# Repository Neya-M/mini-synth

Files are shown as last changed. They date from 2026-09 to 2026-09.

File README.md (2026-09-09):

# mini-synth

A synth but you can only play frequencies received from light, humidity, and temperature sensors.

Schematic:

two of the buttons are upside down for easier routing :P



PCB:



3D View:



BOM:

|Id|Designator|Footprint|Quantity|Designation|Supplier and ref|
|-|-|-|-|-|-|
|1|U4|QFN-20-1EP_4x4mm_P0.5mm_EP2.7x2.7mm|1|MCP23008-xML|https://www.lcsc.com/product-detail/C144211.html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|
|2|C10|C_0402_1005Metric|1|2.2uF|https://www.lcsc.com/product-detail/C170151.html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|
|3|SW3|RotaryEncoder_Alps_EC12E-Switch_Vertical_H20mm|1|volume|https://www.lcsc.com/product-detail/C255515.html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|
|4|J4|PinHeader_1x04_P2.54mm_Vertical|1|weaker pins|no part|
|5|"C31|C32|C17|C3|C2|C4|C13|C18|C1|C19|C16|C6"|C_0402_1005Metric|12|100nF|https://www.lcsc.com/product-detail/C60474.html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|
|6|"R19|R5|R11|R8|R6"|R_0402_1005Metric|5|10K|https://www.lcsc.com/product-detail/C60490.html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|
|7|"C8|C9|C7"|C_0402_1005Metric|3|1uF|https://www.lcsc.com/product-detail/C87145.html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|
|8|"REF**|REF**|REF**"|capacitive touch button 10mm|3|capacitive touch button 10mm|no part|
|9|R21|SW-TH_PRS11R-415F-S103B1|1|20K|https://www.lcsc.com/product-detail/C17371045.html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|
|10|R1|R_LDR_5.1x4.3mm_P3.4mm_Vertical|1|R_Photo|https://www.lcsc.com/product-detail/C125630.html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|
|11|U7|WQFN-16-1EP_3x3mm_P0.5mm_EP1.6x1.6mm_ThermalVias|1|TPA6132A2RTE|https://www.lcsc.com/product-detail/C69901.html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|
|12|SW2|RotaryEncoder_Alps_EC12E-Switch_Vertical_H20mm|1|pitch|https://www.lcsc.com/product-detail/C255515.html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|
|13|SW14|SW-TH_RKJXL100401V|1|SW_Rotary_1x8_MP|https://www.lcsc.com/product-detail/C160838.html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|
|14|"C11|C12|C5"|C_0402_1005Metric|3|4.7uF|https://www.lcsc.com/product-detail/C368809.html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|
|15|C25|C_0402_1005Metric|1|4.7uF|https://www.lcsc.com/product-detail/C368809.html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|
|16|SW7|SW-SMD_L6.1-W3.7-LS8.0-1|1|BOOT|https://www.lcsc.com/product-detail/C49234126.html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|
|17|"R13|R12|R9|R7"|R_0402_1005Metric|4|15K|https://www.lcsc.com/product-detail/C2909322.html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|
|18|"D8|D3|D1|D5|D4|D7|D6|D2"|LED-SMD_4P-L3.2-W2.8-LS5.9_SK6812MINI-E|8|SK6812|https://www.lcsc.com/product-detail/C5149201.html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|
|19|U6|TSSOP-14_L5.0-W4.4-P0.65-LS6.4-BL|1|"74HCT125PW|118"|https://www.lcsc.com/product-detail/C131316.html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|
|20|J1|USB-C-SMD_G-SWITCH_GT-USB-7010ASV|1|USB_C_Receptacle_USB2.0_14P|https://www.lcsc.com/product-detail/C2988369.html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|
|21|SW1|KEY-TH_L12.0-W3.3-P5.00|1|reset|https://www.lcsc.com/product-detail/C2888728.html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|
|22|R20|R_0402_1005Metric|1|330|https://www.lcsc.com/product-detail/C105875.html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|
|23|"D10|D16|D9|D11|D14|D12|D13|D17|D15"|D_0402_1005Metric|9|D|https://www.lcsc.com/product-detail/C28646371.html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|
|24|R22|R_0402_1005Metric|1|1K|https://www.lcsc.com/product-detail/C106235.html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|
|25|SW9|SW-TH_XKB5858-Z-E|1|loop 2|https://www.lcsc.com/product-detail/C780038.html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|
|26|CN1|AUDIO-TH_HOOYA_PJ-320|1|trs headphone jack|https://www.lcsc.com/product-detail/C2939180.html?s_z=n_q_C2939180&globalKeyword=C2939180|
|27|U5|LQFP-48_7x7mm_P0.5mm|1|CH32V203C8T6|https://www.lcsc.com/product-detail/C3001172.html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|
|28|"C30|C29"|C_0402_1005Metric|2|10uF|https://www.lcsc.com/product-detail/C315248.html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|
|29|C23|C_0402_1005Metric|1|10uF|https://www.lcsc.com/product-detail/C315248.html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|
|30|U2|Sensirion_DFN-4_1.5x1.5mm_P0.8mm_SHT4x_NoCentralPad|1|SHT4x|https://www.lcsc.com/product-detail/C55108905.html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|
|31|"C24|C21"|C_0402_1005Metric|2|560pF|https://www.lcsc.com/product-detail/C315248.html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|
|32|"C14|C15"|C_0402_1005Metric|2|47uf|https://www.lcsc.com/product-detail/C140782.html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|
|33|"R16|R15"|R_0402_1005Metric|2|27|https://www.lcsc.com/product-detail/C2100055.html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|
|34|U3|SOT-23|1|MCP1700x-330xxTT|https://www.lcsc.com/product-detail/C144211.html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|
|35|SW10|SW-TH_XKB5858-Z-E|1|record|https://www.lcsc.com/product-detail/C780038.html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|
|36|"R4|R18|R17"|R_0402_1005Metric|3|4.7K|https://www.lcsc.com/product-detail/C105871.html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|
|37|SW12|KEY-TH_L12.0-W3.3-P5.00|1|free1|https://www.lcsc.com/product-detail/C2888728.html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|
|38|SW11|KEY-TH_L12.0-W3.3-P5.00|1|delay|https://www.lcsc.com/product-detail/C2888728.html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|
|39|"R3|R2"|R_0402_1005Metric|2|5.1K|https://www.lcsc.com/product-detail/C105872.html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|
|40|SW13|KEY-TH_L12.0-W3.3-P5.00|1|free2|https://www.lcsc.com/product-detail/C2888728.html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|
|41|R14|R_0402_1005Metric|1|100K|https://www.lcsc.com/product-detail/C60491.html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|
|42|"FB2|FB1"|L0402|2|FerriteBead_Small|https://www.lcsc.com/product-detail/C17701320.html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|
|43|C22|C_0402_1005Metric|1|10nF|https://www.lcsc.com/product-detail/C15195.html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|
|44|U1|DIP-16_W7.62mm|1|PT2399|https://www.lcsc.com/product-detail/C84963.html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|
|45|"C20|C26"|C_0402_1005Metric|2|5.6nF|https://www.lcsc.com/product-detail/C281760.html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|
|46|J2|PinHeader_1x02_P2.54mm_Vertical|1|analog|no part|
|47|SW8|SW-SMD_L6.1-W3.7-LS8.0-1|1|RESET|https://www.lcsc.com/product-detail/C49234126.html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|
|48|"C28|C27"|C_0402_1005Metric|2|12pF|https://www.lcsc.com/product-detail/C26406.html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|
|49|Y1|CRYSTAL-SMD_4P-L3.2-W2.5-BL|1|8MHz|https://www.lcsc.com/product-detail/C2682775.html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|
|50|SW4|SW-SMD_L6.1-W3.7-LS8.0-1|1|reset2|https://www.lcsc.com/product-detail/C49234126.html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|
|51|R10|R_0603_1608Metric|1|2.7K|https://www.lcsc.com/product-detail/C2907008.html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|
|52|J3|PinHeader_1x04_P2.54mm_Vertical|1|debug header|no part|

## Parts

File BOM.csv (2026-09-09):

Id | Designator | Footprint | Quantity | Designation | Supplier and ref
1 | U4 | QFN-20-1EP_4x4mm_P0.5mm_EP2.7x2.7mm | 1 | MCP23008-xML | https://www.lcsc.com/product-detail/C144211.html
2 | C10 | C_0402_1005Metric | 1 | 2.2uF | https://www.lcsc.com/product-detail/C170151.html?s_z=n_q_t_capacitor%25200402
3 | SW3 | RotaryEncoder_Alps_EC12E-Switch_Vertical_H20mm | 1 | volume | https://www.lcsc.com/product-detail/C255515.html?s_z=n_q_t_ec12e
4 | J4 | PinHeader_1x04_P2.54mm_Vertical | 1 | weaker pins | no part
5 | C31,C32,C17,C3,C2,C4,C13,C18,C1,C19,C16,C6 | C_0402_1005Metric | 12 | 100nF | https://www.lcsc.com/product-detail/C60474.html?s_z=n_q_t_capacitor%25200402
6 | R19,R5,R11,R8,R6 | R_0402_1005Metric | 5 | 10K | https://www.lcsc.com/product-detail/C60490.html?s_z=n_q_t_resistor%25200402
7 | C8,C9,C7 | C_0402_1005Metric | 3 | 1uF | https://www.lcsc.com/product-detail/C87145.html?s_z=n_q_t_capacitor%25200402
8 | REF**,REF**,REF** | capacitive touch button 10mm | 3 | capacitive touch button 10mm | no part
9 | R21 | SW-TH_PRS11R-415F-S103B1 | 1 | 20K | https://www.lcsc.com/product-detail/C17371045.html
10 | R1 | R_LDR_5.1x4.3mm_P3.4mm_Vertical | 1 | R_Photo | https://www.lcsc.com/product-detail/C125630.html
11 | U7 | WQFN-16-1EP_3x3mm_P0.5mm_EP1.6x1.6mm_ThermalVias | 1 | TPA6132A2RTE | https://www.lcsc.com/product-detail/C69901.html?s_z=n_q_TPA6132A2RTE
12 | SW2 | RotaryEncoder_Alps_EC12E-Switch_Vertical_H20mm | 1 | pitch | https://www.lcsc.com/product-detail/C255515.html?s_z=n_q_t_ec12e
13 | SW14 | SW-TH_RKJXL100401V | 1 | SW_Rotary_1x8_MP | https://www.lcsc.com/product-detail/C160838.html
14 | C11,C12,C5 | C_0402_1005Metric | 3 | 4.7uF | https://www.lcsc.com/product-detail/C368809.html?s_z=n_q_t_capacitor%25200402
15 | C25 | C_0402_1005Metric | 1 | 4.7uF | https://www.lcsc.com/product-detail/C368809.html?s_z=n_q_t_capacitor%25200402
16 | SW7 | SW-SMD_L6.1-W3.7-LS8.0-1 | 1 | BOOT | https://www.lcsc.com/product-detail/C49234126.html
17 | R13,R12,R9,R7 | R_0402_1005Metric | 4 | 15K | https://www.lcsc.com/product-detail/C2909322.html?s_z=n_q_t_resistor%25200402
18 | D8,D3,D1,D5,D4,D7,D6,D2 | LED-SMD_4P-L3.2-W2.8-LS5.9_SK6812MINI-E | 8 | SK6812 | https://www.lcsc.com/product-detail/C5149201.html?s_z=n_q_l_SK6812%2520mini%2520e
19 | U6 | TSSOP-14_L5.0-W4.4-P0.65-LS6.4-BL | 1 | 74HCT125PW,118 | https://www.lcsc.com/product-detail/C131316.html
20 | J1 | USB-C-SMD_G-SWITCH_GT-USB-7010ASV | 1 | USB_C_Receptacle_USB2.0_14P | https://www.lcsc.com/product-detail/C2988369.html
21 | SW1 | KEY-TH_L12.0-W3.3-P5.00 | 1 | reset | https://www.lcsc.com/product-detail/C2888728.html
22 | R20 | R_0402_1005Metric | 1 | 330 | https://www.lcsc.com/product-detail/C105875.html?s_z=n_q_t_resistor%25200402
23 | D10,D16,D9,D11,D14,D12,D13,D17,D15 | D_0402_1005Metric | 9 | D | https://www.lcsc.com/product-detail/C28646371.html?s_z=n_q_t_diode
24 | R22 | R_0402_1005Metric | 1 | 1K | https://www.lcsc.com/product-detail/C106235.html?s_z=n_q_t_resistor%25200402
25 | SW9 | SW-TH_XKB5858-Z-E | 1 | loop 2 | https://www.lcsc.com/product-detail/C780038.html
26 | CN1 | AUDIO-TH_HOOYA_PJ-320 | 1 | trs headphone jack | https://www.lcsc.com/product-detail/C2939180.html?s_z=n_q_C2939180&globalKeyword=C2939180
27 | U5 | LQFP-48_7x7mm_P0.5mm | 1 | CH32V203C8T6 | https://www.lcsc.com/product-detail/C3001172.html
28 | C30,C29 | C_0402_1005Metric | 2 | 10uF | https://www.lcsc.com/product-detail/C315248.html?s_z=n_q_t_capacitor%25200402
29 | C23 | C_0402_1005Metric | 1 | 10uF | https://www.lcsc.com/product-detail/C315248.html?s_z=n_q_t_capacitor%25200402
30 | U2 | Sensirion_DFN-4_1.5x1.5mm_P0.8mm_SHT4x_NoCentralPad | 1 | SHT4x | https://www.lcsc.com/product-detail/C55108905.html?s_z=n_q_t_sht4
31 | C24,C21 | C_0402_1005Metric | 2 | 560pF | https://www.lcsc.com/product-detail/C315248.html?s_z=n_q_t_capacitor%25200402
32 | C14,C15 | C_0402_1005Metric | 2 | 47uf | https://www.lcsc.com/product-detail/C140782.html?s_z=n_q_t_47%2520uF%2520capacitor
33 | R16,R15 | R_0402_1005Metric | 2 | 27 | https://www.lcsc.com/product-detail/C2100055.html?s_z=n_q_t_resistor%25200402
34 | U3 | SOT-23 | 1 | MCP1700x-330xxTT | https://www.lcsc.com/product-detail/C144211.html
35 | SW10 | SW-TH_XKB5858-Z-E | 1 | record | https://www.lcsc.com/product-detail/C780038.html
36 | R4,R18,R17 | R_0402_1005Metric | 3 | 4.7K | https://www.lcsc.com/product-detail/C105871.html?s_z=n_q_t_resistor%25200402
37 | SW12 | KEY-TH_L12.0-W3.3-P5.00 | 1 | free1 | https://www.lcsc.com/product-detail/C2888728.html
38 | SW11 | KEY-TH_L12.0-W3.3-P5.00 | 1 | delay | https://www.lcsc.com/product-detail/C2888728.html
39 | R3,R2 | R_0402_1005Metric | 2 | 5.1K | https://www.lcsc.com/product-detail/C105872.html?s_z=n_q_t_resistor%25200402
40 | SW13 | KEY-TH_L12.0-W3.3-P5.00 | 1 | free2 | https://www.lcsc.com/product-detail/C2888728.html
41 | R14 | R_0402_1005Metric | 1 | 100K | https://www.lcsc.com/product-detail/C60491.html?s_z=n_q_t_resistor%25200402
42 | FB2,FB1 | L0402 | 2 | FerriteBead_Small | https://www.lcsc.com/product-detail/C17701320.html
43 | C22 | C_0402_1005Metric | 1 | 10nF | https://www.lcsc.com/product-detail/C15195.html?s_z=n_q_t_capacitor%25200402
44 | U1 | DIP-16_W7.62mm | 1 | PT2399 | https://www.lcsc.com/product-detail/C84963.html?s_z=n_q_x_pt2399
45 | C20,C26 | C_0402_1005Metric | 2 | 5.6nF | https://www.lcsc.com/product-detail/C281760.html?s_z=n_q_t_capacitor%25200402
46 | J2 | PinHeader_1x02_P2.54mm_Vertical | 1 | analog | no part
47 | SW8 | SW-SMD_L6.1-W3.7-LS8.0-1 | 1 | RESET | https://www.lcsc.com/product-detail/C49234126.html
48 | C28,C27 | C_0402_1005Metric | 2 | 12pF | https://www.lcsc.com/product-detail/C26406.html?s_z=n_q_t_capacitor%25200402
49 | Y1 | CRYSTAL-SMD_4P-L3.2-W2.5-BL | 1 | 8MHz | https://www.lcsc.com/product-detail/C2682775.html
50 | SW4 | SW-SMD_L6.1-W3.7-LS8.0-1 | 1 | reset2 | https://www.lcsc.com/product-detail/C49234126.html
51 | R10 | R_0603_1608Metric | 1 | 2.7K | https://www.lcsc.com/product-detail/C2907008.html?s_z=n_q_t_resistor%25200603%25202.7k
52 | J3 | PinHeader_1x04_P2.54mm_Vertical | 1 | debug header | no part

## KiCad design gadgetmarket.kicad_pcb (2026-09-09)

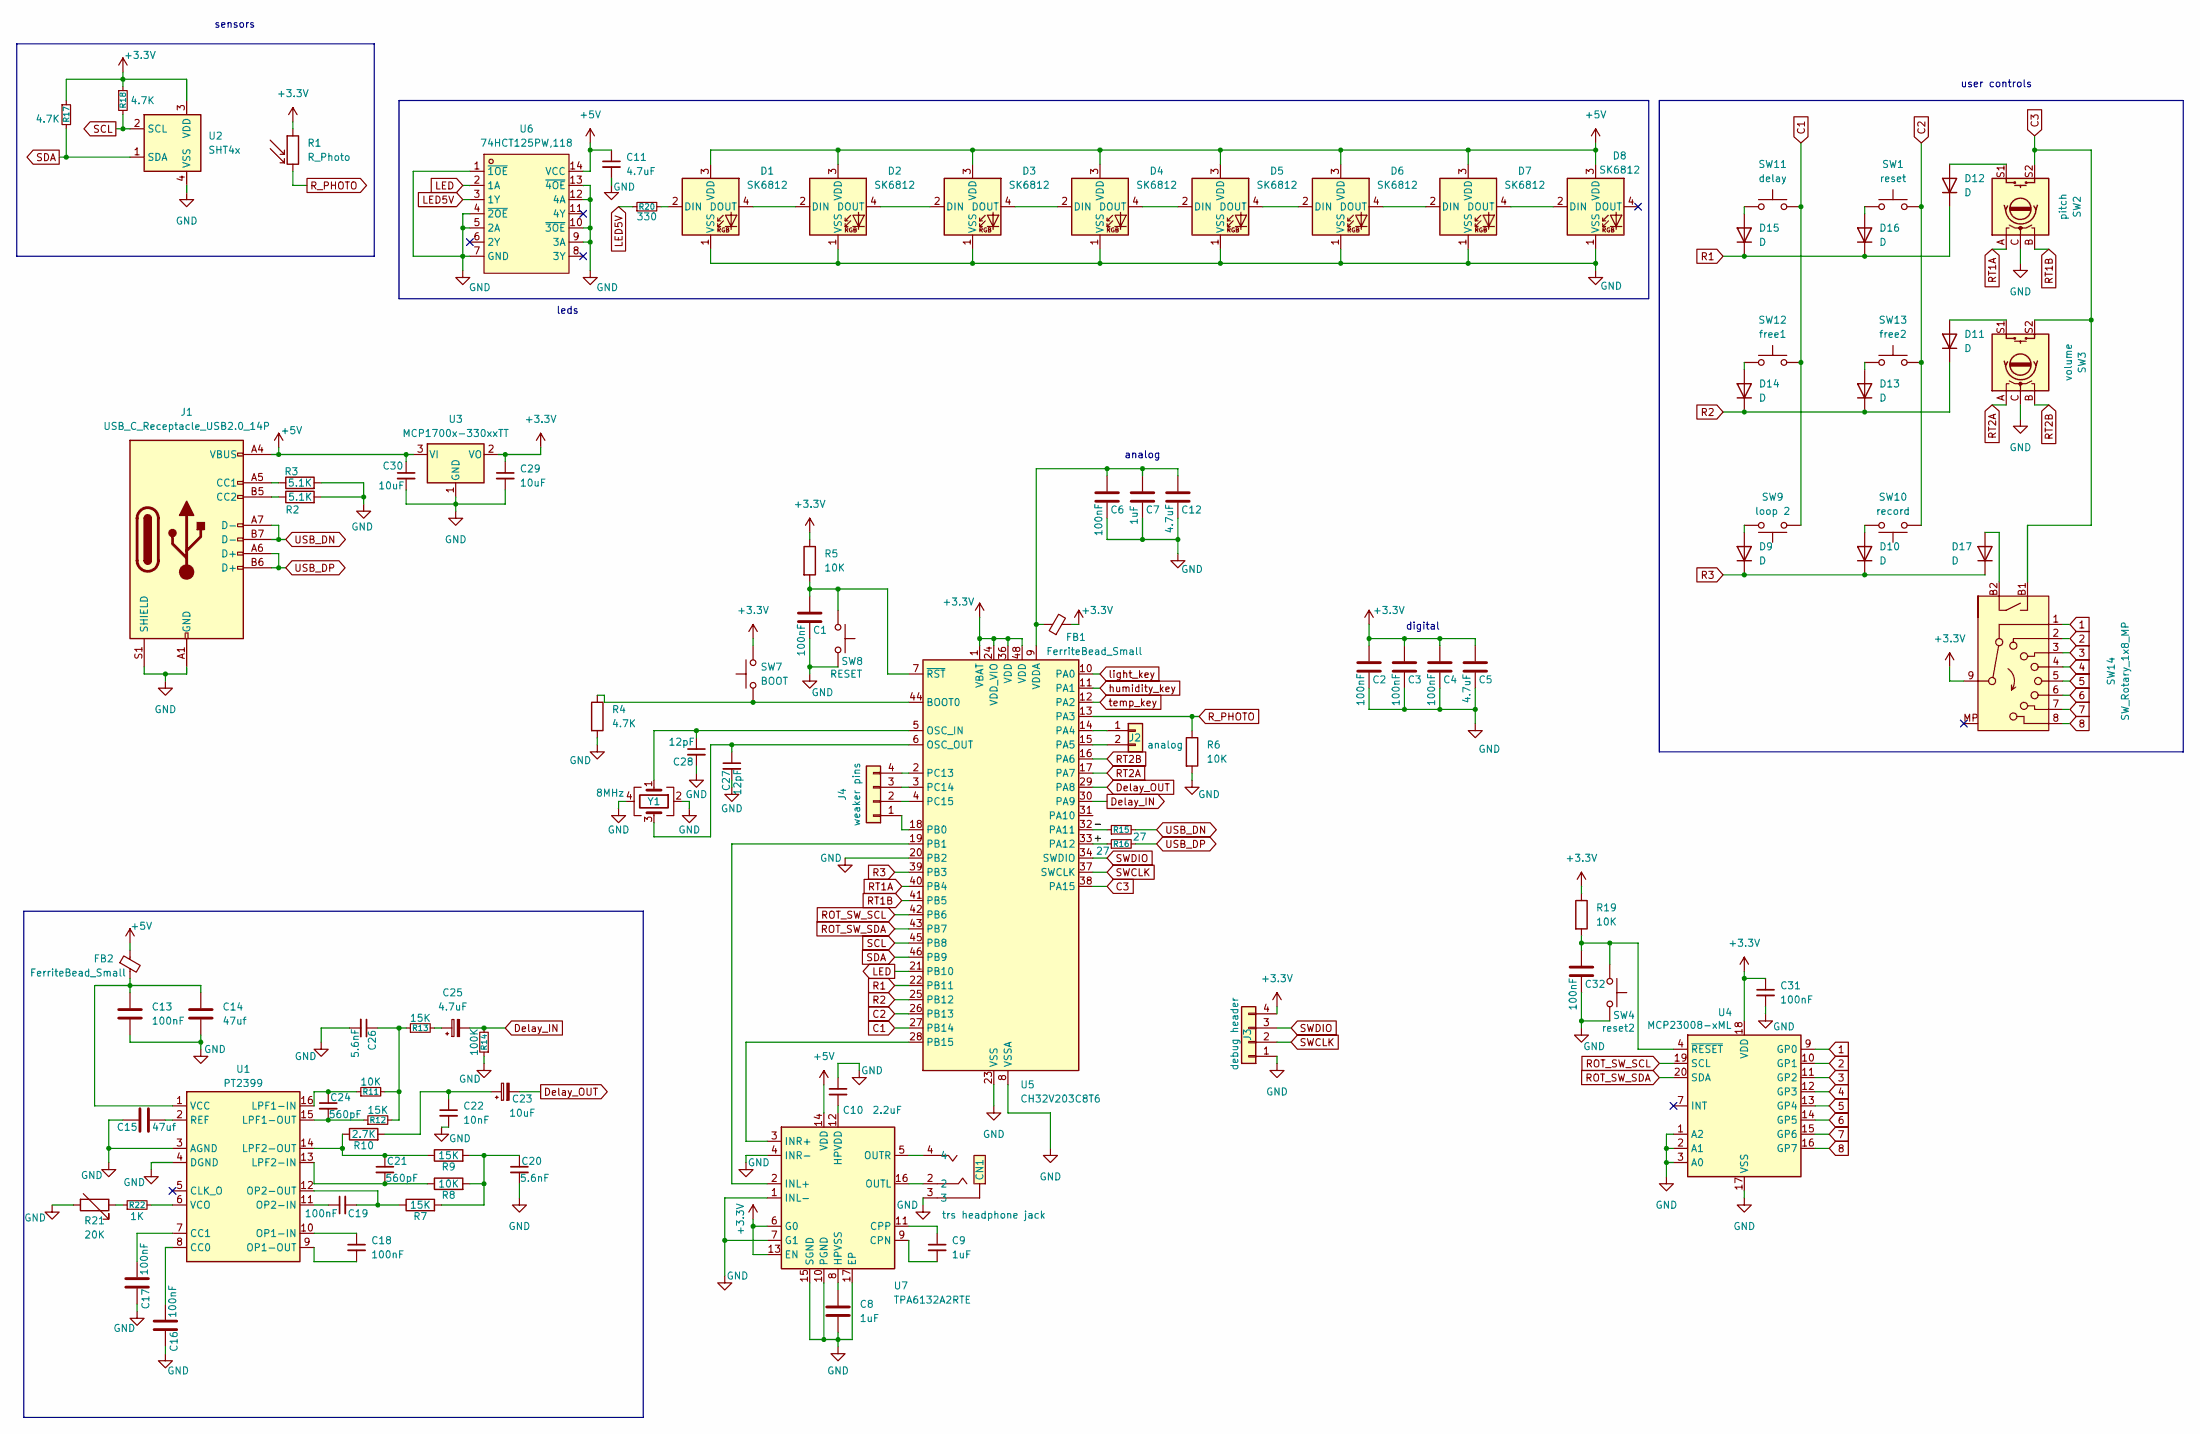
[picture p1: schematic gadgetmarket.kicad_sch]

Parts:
C1, C2, C3, C4, C6, C13, C16, C17, C18, C19, C31, C32: 100nF; C_0402_1005Metric
C5, C11, C12, C25: 4.7uF; C_0402_1005Metric
C7, C8, C9: 1uF; C_0402_1005Metric
C10: 2.2uF; C_0402_1005Metric
C14, C15: 47uf; C_0603_1608Metric
C20, C26: 5.6nF; C_0402_1005Metric
C21, C24: 560pF; C_0402_1005Metric
C22: 10nF; C_0402_1005Metric
C23, C29, C30: 10uF; C_0402_1005Metric
C27, C28: 12pF; C_0402_1005Metric
CN1: trs headphone jack; AUDIO-TH_HOOYA_PJ-320; MPN PJ-320(OS); LCSC Part C2939180
D1, D2, D3, D4, D5, D6, D7, D8: SK6812; LED-SMD_4P-L3.2-W2.8-LS5.9_SK6812MINI-E
D9, D10, D11, D12, D13, D14, D15, D16, D17: D; D_0402_1005Metric
FB1, FB2: FerriteBead_Small; L0402
J1: USB_C_Receptacle_USB2.0_14P; USB-C-SMD_G-SWITCH_GT-USB-7010ASV
J2: analog; PinHeader_1x02_P2.54mm_Vertical
J3: debug header; PinHeader_1x04_P2.54mm_Vertical
J4: weaker pins; PinHeader_1x04_P2.54mm_Vertical
R1: R_Photo; R_LDR_5.1x4.3mm_P3.4mm_Vertical
R2, R3: 5.1K; R_0402_1005Metric
R4, R17, R18: 4.7K; R_0402_1005Metric
R5, R6, R8, R11, R19: 10K; R_0402_1005Metric
R7, R9, R12, R13: 15K; R_0402_1005Metric
R10: 2.7K; R_0603_1608Metric
R14: 100K; R_0402_1005Metric
R15, R16: 27; R_0402_1005Metric
R20: 330; R_0402_1005Metric
R21: 20K; SW-TH_PRS11R-415F-S103B1
R22: 1K; R_0402_1005Metric
SW1: reset; KEY-TH_L12.0-W3.3-P5.00
SW2: pitch; RotaryEncoder_Alps_EC12E-Switch_Vertical_H20mm
SW3: volume; RotaryEncoder_Alps_EC12E-Switch_Vertical_H20mm
SW4: reset2; SW-SMD_L6.1-W3.7-LS8.0-1
SW7: BOOT; SW-SMD_L6.1-W3.7-LS8.0-1
SW8: RESET; SW-SMD_L6.1-W3.7-LS8.0-1
SW9: loop 2; SW-TH_XKB5858-Z-E
SW10: record; SW-TH_XKB5858-Z-E
SW11: delay; KEY-TH_L12.0-W3.3-P5.00
SW12: free1; KEY-TH_L12.0-W3.3-P5.00
SW13: free2; KEY-TH_L12.0-W3.3-P5.00
SW14: SW_Rotary_1x8_MP; SW-TH_RKJXL100401V
U1: PT2399; DIP-16_W7.62mm
U2: SHT4x; Sensirion_DFN-4_1.5x1.5mm_P0.8mm_SHT4x_NoCentralPad
U3: MCP1700x-330xxTT; SOT-23
U4: MCP23008-xML; QFN-20-1EP_4x4mm_P0.5mm_EP2.7x2.7mm
U5: CH32V203C8T6; LQFP-48_7x7mm_P0.5mm
U6: 74HCT125PW,118; TSSOP-14_L5.0-W4.4-P0.65-LS6.4-BL; MPN 74HCT125PW,118; LCSC Part C131316
U7: TPA6132A2RTE; WQFN-16-1EP_3x3mm_P0.5mm_EP1.6x1.6mm_ThermalVias
Y1: 8MHz; CRYSTAL-SMD_4P-L3.2-W2.5-BL

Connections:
1: SW14.1, U4.9 (GP0)
2: SW14.2, U4.10 (GP1)
3: SW14.3, U4.11 (GP2)
4: SW14.4, U4.12 (GP3)
5: SW14.5, U4.13 (GP4)
6: SW14.6, U4.14 (GP5)
7: SW14.7, U4.15 (GP6)
8: SW14.8, U4.16 (GP7)
+3.3V: C2.1, C3.1, C4.1, C5.1, C29.1, C31.1, FB1.2, J3.4, R1.1, R5.1, R17.1, R18.1, R19.1, SW7.2, SW14.9, U2.3 (VDD), U3.2 (VO), U4.18 (VDD), U5.1 (VBAT), U5.24 (VDD_VIO), U5.36 (VDD), U5.48 (VDD), U7.6 (G0), U7.13 (EN)
+5V: C11.1, C30.1, D1.3 (VDD), D2.3 (VDD), D3.3 (VDD), D4.3 (VDD), D5.3 (VDD), D6.3 (VDD), D7.3 (VDD), D8.3 (VDD), FB2.1, J1.A4 (VBUS), J1.A9 (VBUS), J1.B4 (VBUS), J1.B9 (VBUS), U3.3 (VI), U6.14 (VCC), U7.14 (VDD)
/+: R16.1, U5.33 (PA12)
/-: R15.1, U5.32 (PA11)
C1: SW9.4, SW11.2, SW12.2, U5.27 (PB14)
C2: SW1.2, SW10.4, SW13.2, U5.26 (PB13)
C3: SW2.S2, SW3.S2, SW14.B1, U5.38 (PA15)
Delay_IN: C25.2, R14.2, U5.30 (PA9)
Delay_OUT: C23.2, U5.29 (PA8)
GND: C1.2, C2.2, C3.2, C4.2, C5.2, C6.2, C7.2, C8.2, C10.1, C11.2, C12.2, C13.2, C14.2, C15.1, C16.2, C17.2, C20.2, C22.2, C26.2, C27.2, C28.2, C29.2, C30.2, C31.2, C32.2, CN1.3, D1.1 (VSS), D2.1 (VSS), D3.1 (VSS), D4.1 (VSS), D5.1 (VSS), D6.1 (VSS), D7.1 (VSS), D8.1 (VSS), J1.A1 (GND), J1.A12 (GND), J1.B1 (GND), J1.B12 (GND), J1.S1 (SHIELD), J3.1, R2.2, R3.2, R4.2, R6.2, R14.1, R21.2, SW2.C, SW3.C, SW4.2, SW8.2, U1.3 (AGND), U1.4 (DGND), U2.4 (VSS), U3.1 (GND), U4.1 (A2), U4.2 (A1), U4.3 (A0), U4.17 (VSS), U4.21, U5.8 (VSSA), U5.20 (PB2), U5.23 (VSS), U5.35 (VSS), U5.47 (VSS), U6.1 (~1OE), U6.4 (~2OE), U6.5 (2A), U6.7 (GND), U6.9 (3A), U6.10 (~3OE), U6.12 (4A), U6.13 (~4OE), U7.1 (INL-), U7.4 (INR-), U7.7 (G1), U7.10 (PGND), U7.15 (SGND), U7.17 (EP), Y1.2, Y1.4
LED: U5.21 (PB10), U6.2 (1A)
LED5V: R20.1, U6.3 (1Y)
unnamed: C20.1, R7.2, R8.2, R9.2
unnamed: C22.1, C23.1, R10.2
unnamed: C25.1, R13.2
unnamed: C26.1, R11.2, R12.2, R13.1
unnamed: D1.2 (DIN), R20.2
unnamed: D1.4 (DOUT), D2.2 (DIN)
unnamed: D2.4 (DOUT), D3.2 (DIN)
unnamed: D3.4 (DOUT), D4.2 (DIN)
unnamed: D4.4 (DOUT), D5.2 (DIN)
unnamed: D5.4 (DOUT), D6.2 (DIN)
unnamed: D6.4 (DOUT), D7.2 (DIN)
unnamed: D7.4 (DOUT), D8.2 (DIN)
unnamed: D9.2 (A), SW9.2
unnamed: D10.2 (A), SW10.2
unnamed: D11.2 (A), SW3.S1
unnamed: D12.2 (A), SW2.S1
unnamed: D13.2 (A), SW13.1
unnamed: D14.2 (A), SW12.1
unnamed: D15.2 (A), SW11.1
unnamed: D16.2 (A), SW1.1
unnamed: D17.2 (A), SW14.B2
unnamed: J1.A5 (CC1), R3.1
unnamed: J1.B5 (CC2), R2.1
unnamed: J2.1, U5.14 (PA4)
unnamed: J2.2, U5.15 (PA5)
unnamed: J4.1, U5.18 (PB0)
unnamed: J4.2, U5.4 (PC15)
unnamed: J4.3, U5.3 (PC14)
unnamed: J4.4, U5.2 (PC13)
unnamed: R21.1, R22.1
unnamed: C16.1, U1.8 (CC0)
unnamed: C17.1, U1.7 (CC1)
unnamed: C24.1, R11.1, U1.16 (LPF1-IN)
unnamed: C24.2, R12.1, U1.15 (LPF1-OUT)
unnamed: C21.2, R8.1, U1.13 (LPF2-IN)
unnamed: C21.1, R9.1, R10.1, U1.14 (LPF2-OUT)
unnamed: C18.1, U1.10 (OP1-IN)
unnamed: C18.2, U1.9 (OP1-OUT)
unnamed: C19.1, U1.11 (OP2-IN)
unnamed: C19.2, R7.1, U1.12 (OP2-OUT)
unnamed: C15.2, U1.2 (REF)
unnamed: C13.1, C14.1, FB2.2, U1.1 (VCC)
unnamed: R22.2, U1.6 (VCO)
unnamed: C32.1, R19.2, SW4.1, U4.4 (~RESET)
unnamed: R4.1, SW7.1, U5.44 (BOOT0)
unnamed: C28.1, U5.5 (OSC_IN), Y1.1
unnamed: C27.1, U5.6 (OSC_OUT), Y1.3
unnamed: U5.19 (PB1), U7.2 (INL+)
unnamed: U5.28 (PB15), U7.3 (INR+)
unnamed: C6.1, C7.1, C12.1, FB1.1, U5.9 (VDDA)
unnamed: C1.1, R5.2, SW8.1, U5.7 (~RST)
unnamed: C9.2, U7.9 (CPN)
unnamed: C9.1, U7.11 (CPP)
unnamed: C10.2, U7.12 (HPVDD)
unnamed: C8.1, U7.8 (HPVSS)
unnamed: CN1.2, U7.16 (OUTL)
unnamed: CN1.4, U7.5 (OUTR)
R1: D12.1 (K), D15.1 (K), D16.1 (K), U5.22 (PB11)
R2: D11.1 (K), D13.1 (K), D14.1 (K), U5.25 (PB12)
R3: D9.1 (K), D10.1 (K), D17.1 (K), U5.39 (PB3)
ROT_SW_SCL: U4.19 (SCL), U5.42 (PB6)
ROT_SW_SDA: U4.20 (SDA), U5.43 (PB7)
RT1A: SW2.A, U5.40 (PB4)
RT1B: SW2.B, U5.41 (PB5)
RT2A: SW3.A, U5.17 (PA7)
RT2B: SW3.B, U5.16 (PA6)
R_PHOTO: R1.2, R6.1, U5.13 (PA3)
SCL: R18.2, U2.2 (SCL), U5.45 (PB8)
SDA: R17.2, U2.1 (SDA), U5.46 (PB9)
SWCLK: J3.2, U5.37 (SWCLK)
SWDIO: J3.3, U5.34 (SWDIO)
USB_DN: J1.A7 (D-), J1.B7 (D-), R15.2
USB_DP: J1.A6 (D+), J1.B6 (D+), R16.2
humidity_key: U5.11 (PA1)
light_key: U5.10 (PA0)
temp_key: U5.12 (PA2)

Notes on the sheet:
digital
sensors
user controls
leds
analog

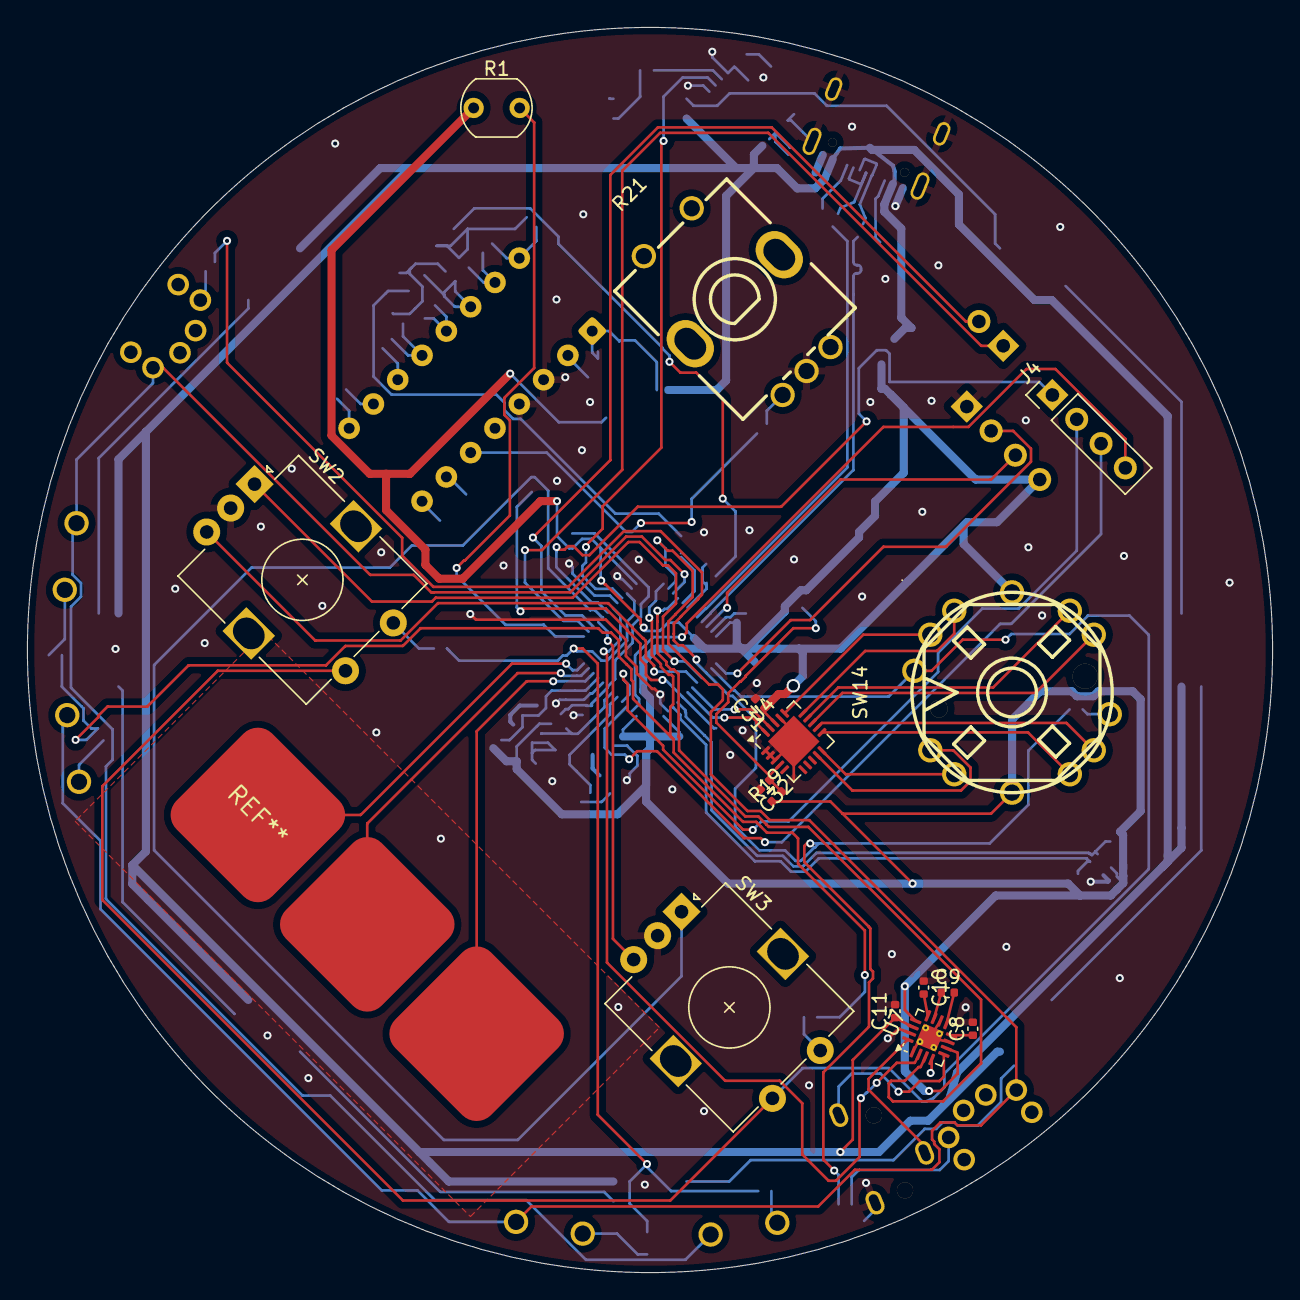
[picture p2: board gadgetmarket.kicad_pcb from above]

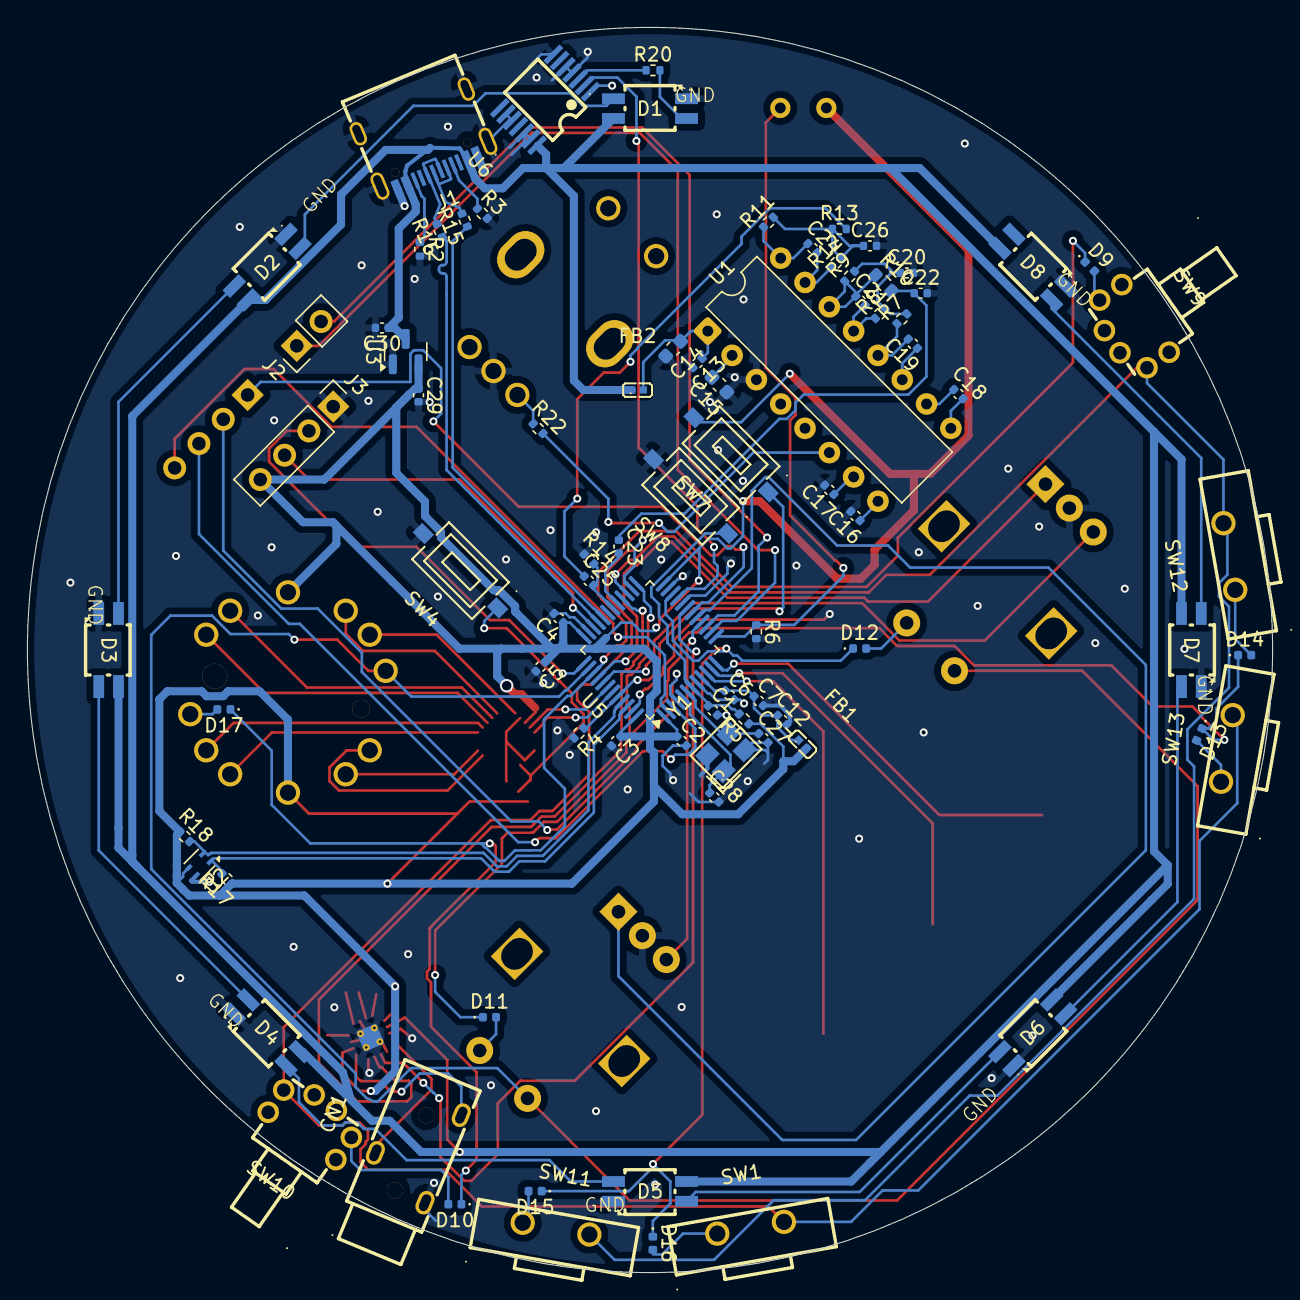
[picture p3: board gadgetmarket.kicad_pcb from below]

Board: 2 copper layers, 92.0 x 92.0 mm, 98 parts (83 on the bottom side), 93 nets.
